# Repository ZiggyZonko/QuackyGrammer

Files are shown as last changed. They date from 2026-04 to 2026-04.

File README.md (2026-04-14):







# QuackyGrammer ~ The portable, Type C PIC Programmer

Recently, I rediscovered a collection of PIC Microcontrollers and was fascinated on how they work, programming them, and the simplicity of a REAL microcontroller. Before this, I was learning assembly through a previous project of mine, LindlesOS, so these microcontrollers were a great way of demonstrating the practicality of Assembly. I picked up a k150 from AliExpress, only to realise the drivers are impossible to find, setup and are mind-numbing to install...

This is what brought me to my project, I was wondering, how could I improve the programming of PIC Microcontrollers while making it portable, and simplistic. I stumbled upon the PICKIT 2 and learnt about the difference between ZIF and ISCP sockets, learning that ISCP was wayyy more accessible, and may be suitable for my project. After countless hours of planning, wondering, and researching I agreed on things to include in my project

- USB Type C Connector ~ Usually on programmers they use USB Type B because of it's constant power rather than being wired to power.
  
- PIC18F2550 ~ The heart and brains of the project. The K150 uses PIC16F628A but I wanted to add further programming capabilities and not include excess chips, like on the K150.
  
- Connector ~ The defining factor of the PICKIT 2 is the ability to plug about 5 wires into the microcontroller, and upload your code from a PICKIT application, which is exactly what I can replicate with this project, for even more accessibility.

Which brings me to my project, QuackyGrammer ✨

The QuackyGrammer is a USB Type C powered, portable, ISCP connecting PIC Programmer, powered by the mighty PIC18F2550. The Programmer is aimed to make PIC Programming easy with a flawless, PICKIT 2 inspired connecting system, and a very portable USB Type C connection port. The duck theme is inspired by a new nickname I recently acquired, Quackery, and as you can tell by my other projects, I stick with this theme now.

The Bill of Materials is in BOM.csv

The firmware for this project, is uploading the PK2V023200.hex into the PIC18F2550 with the PICKITV2 programmer software.

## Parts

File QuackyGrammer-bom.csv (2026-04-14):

Name | Purpose | Quantity | Total Cost (USD) | Link | Distributor
JLCPCB PCB Project | The PCB of the Project | 5 | 2.00 | https://cart.jlcpcb.com/shopcart/cart | JLCPCB
470nF 50VDC Low Leakage Electrolytic Capacitor | VUSB Connection | 1 | 0.34 | https://www.jaycar.com.au/p/RL6410 | Jaycar
47uF 16VDC Electrolytic Capacitor | Power and Boost Module Capacitors | 3 | 0.75 | https://www.jaycar.com.au/p/RE6100 | Jaycar
20.0 MHz Crystal | Crystal Oscillator | 1 | 2.10 | https://www.jaycar.com.au/p/RQ5299 | Jaycar
680uH RF Choke | Inductor For Boost Module | 1 | 0.68 | https://www.jaycar.com.au/p/LF1544 | Jaycar
100nF 50VDC Ceramic Capacitors ~ Pack of 2 | Power Capacitors | 1 | 0.39 | https://www.jaycar.com.au/p/RC5360 | Jaycar
BC548 NPN Transistor | Boost Module | 3 | 0.64 | https://www.jaycar.com.au/p/ZT2154 | Jaycar
BC557 PNP Transistor | Boost Module Transistor | 1 | 0.21 | https://www.jaycar.com.au/p/ZT2164 | Jaycar
6 Pin 0.1 inch Header | The ISCP Header Connection | 1 | 0.68 | https://www.jaycar.com.au/p/HM3406 | Jaycar
28 Pin Production IC Socket | Securing the PIC18F2550 | 1 | 0.53 | https://www.jaycar.com.au/p/PI6510 | Jaycar
Red 3mm LED | Power Off/Error Indicator | 1 | 0.53 | https://www.jaycar.com.au/p/ZD0102 | Jaycar
Green 3mm LED | Green LED for Power On | 1 | 0.53 | https://www.jaycar.com.au/p/ZD0122 | Jaycar
15pF 50VDC Ceramic Capacitors ~ 2 Pack | Crystal Capacitors | 1 | 0.32 | https://www.jaycar.com.au/p/RC5314 | Jaycar
Tactile Switch | Reset Switch for PIC18F2550 | 1 | 0.68 | https://www.jaycar.com.au/p/SP0611 | Jaycar
1N4148 Signal Diode Pack of 5 | Boost Module Diode | 1 | 0.68 | https://www.jaycar.com.au/p/ZR1100 | Jaycar
10uF 25VDC Electrolytic Capacitor | Power Capacitor | 1 | 0.25 | https://www.jaycar.com.au/p/RE6070 | Jaycar
E12 1/4 Watt Resistor Kit | Used for Resistors in the PCB | 1 | 16.34 | https://www.jaycar.com.au/p/RR1697 | Jaycar
5.1k Ohm Resistor Pack of 8 | USB Data Resistor Specifically | 1 | 0.61 | https://www.jaycar.com.au/5-1k-ohm-0-5-watt-metal-film-resistors-pack-of-8/p/RR0589 | Jaycar
USB Connector Type C | The USB connector, giving power and data to the project | 1 | 0.78 | https://www.digikey.com.au/en/products/detail/gct/USB4105-GF-A/11198441 | Digikey
PIC18F2550 | The heart of the project, powering the programming | 1 | 7.04 | https://www.digikey.com.au/en/products/detail/microchip-technology/PIC18F2550-I-SP/704575 | Digikey

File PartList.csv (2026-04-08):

Item | Quantity | Value/Part | Description | Package | Notes
U1 | 1 | PIC18F2550-I/P | Microcontroller DIP-28 | DIP-28 | Main MCU
U1-Socket | 1 | 28-pin IC socket | DIP socket | DIP-28 | For MCU
J1 | 1 | USB-C Receptacle (USB2.0) | USB connector | USB-C TH/SMD | Power + data
J2 | 1 | Pin Header 1x6 | ICSP Header | 2.54mm | Programming header
Y1 | 1 | 20MHz Crystal | Crystal oscillator | HC-49 | Clock
C1-C2 | 2 | 15pF | Ceramic capacitor | Through-hole | Crystal caps
C3-C4 | 2 | 100nF | Ceramic capacitor | Through-hole | Decoupling
C5-C6 | 2 | 47uF 16V | Electrolytic capacitor | Radial | Power smoothing
C7 | 1 | 10uF 16V | Electrolytic capacitor | Radial | Power
C8 | 1 | 470nF | Ceramic capacitor | Through-hole | USB filter
R1-R2 | 2 | 22Ω | Resistor | Through-hole | USB data lines
R3-R4 | 2 | 5.1kΩ | Resistor | Through-hole | USB-C CC pull-down
R5-R7 | 3 | 33Ω | Resistor | Through-hole | General
R8 | 1 | 100Ω | Resistor | Through-hole | General
R9 | 1 | 1kΩ | Resistor | Through-hole | General
R10 | 1 | 2.7kΩ | Resistor | Through-hole | General
R11-R12 | 2 | 4.7kΩ | Resistor | Through-hole | General
R13-R15 | 3 | 10kΩ | Resistor | Through-hole | General
R16 | 1 | 100kΩ | Resistor | Through-hole | General
R17-R18 | 2 | 330Ω | Resistor | Through-hole | LED current limit
D1-D2 | 2 | 1N4148 | Diode | DO-35 | Signal diode
Q1-Q3 | 3 | BC548 | NPN Transistor | TO-92 | VPP circuit
Q4 | 1 | BC557 | PNP Transistor | TO-92 | VPP circuit
L1 | 1 | 680uH | Inductor | Axial | Boost circuit
LED1 | 1 | Green LED | Indicator LED | 3mm | Status
LED2 | 1 | Red LED | Indicator LED | 3mm | Status
SW1 | 1 | Tactile Switch | Push button | Through-hole | User input
HW1 | 4 | M3x10mm Screw | Machine screw | Metal | Case assembly

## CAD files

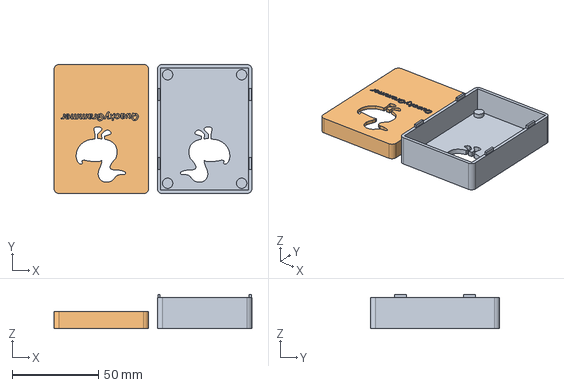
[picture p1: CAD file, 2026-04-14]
Model/QuackyGrammerModelOnly.step
115.0 x 75.0 x 20.0 mm

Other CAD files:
Model/QuackGrammer.step

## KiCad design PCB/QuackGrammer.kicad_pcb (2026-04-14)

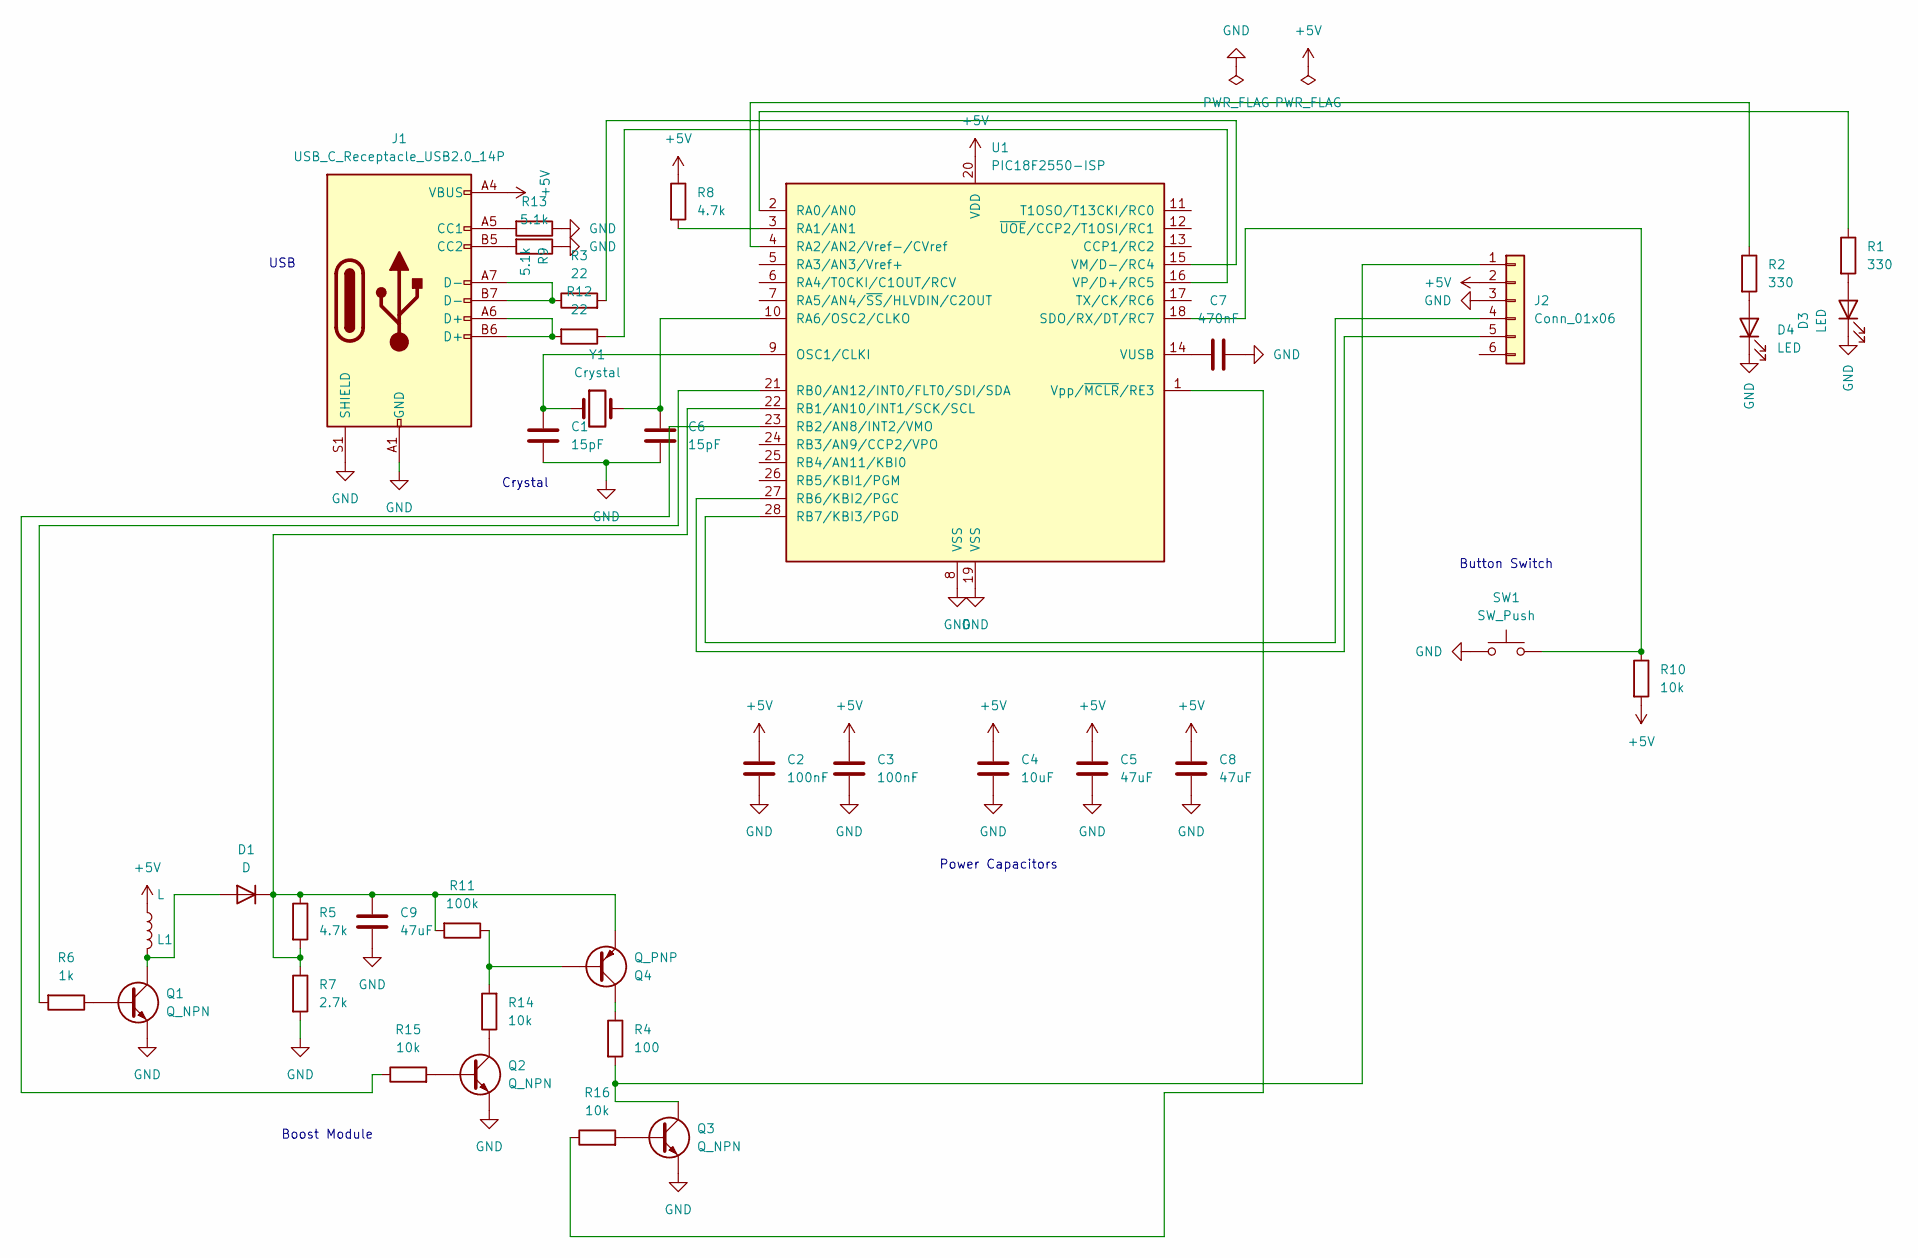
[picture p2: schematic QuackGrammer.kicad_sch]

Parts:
C1, C6: 15pF; C_Disc_D5.0mm_W2.5mm_P5.00mm
C2, C3: 100nF; C_Disc_D5.0mm_W2.5mm_P5.00mm
C4: 10uF; CP_Radial_D5.0mm_P2.50mm
C5, C8, C9: 47uF; CP_Radial_D5.0mm_P2.50mm
C7: 470nF; C_Disc_D5.0mm_W2.5mm_P5.00mm
D1: D; D_DO-35_SOD27_P7.62mm_Horizontal
D3, D4: LED; LED_D3.0mm
J1: USB_C_Receptacle_USB2.0_14P; USB_C_Receptacle_GCT_USB4105-xx-A_16P_TopMnt_Horizontal
J2: Conn_01x06; PinHeader_1x06_P2.54mm_Horizontal
L1: L; R_Axial_DIN0207_L6.3mm_D2.5mm_P7.62mm_Horizontal
Q1, Q2, Q3: Q_NPN; TO-92_Inline
Q4: Q_PNP; TO-92_Inline
R1, R2: 330; R_Axial_DIN0207_L6.3mm_D2.5mm_P7.62mm_Horizontal
R3, R12: 22; R_Axial_DIN0207_L6.3mm_D2.5mm_P7.62mm_Horizontal
R4: 100; R_Axial_DIN0207_L6.3mm_D2.5mm_P7.62mm_Horizontal
R5, R8: 4.7k; R_Axial_DIN0207_L6.3mm_D2.5mm_P7.62mm_Horizontal
R6: 1k; R_Axial_DIN0207_L6.3mm_D2.5mm_P7.62mm_Horizontal
R7: 2.7k; R_Axial_DIN0207_L6.3mm_D2.5mm_P7.62mm_Horizontal
R9, R13: 5.1k; R_Axial_DIN0207_L6.3mm_D2.5mm_P7.62mm_Horizontal
R10, R14, R15, R16: 10k; R_Axial_DIN0207_L6.3mm_D2.5mm_P7.62mm_Horizontal
R11: 100k; R_Axial_DIN0207_L6.3mm_D2.5mm_P7.62mm_Horizontal
SW1: SW_Push; SW_PUSH_6mm
U1: PIC18F2550-ISP; DIP-28_W7.62mm
Y1: Crystal; Crystal_HC49-U_Vertical

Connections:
+5V: C2.1, C3.1, C4.1, C5.1, C8.1, J1.A4 (VBUS), J1.A9 (VBUS), J1.B4 (VBUS), J1.B9 (VBUS), J2.2, L1.2, R8.1, R10.2, U1.20 (VDD)
GND: C1.2, C2.2, C3.2, C4.2, C5.2, C6.2, C7.1, C8.2, C9.2, D3.1 (K), D4.1 (K), J1.A1 (GND), J1.A12 (GND), J1.B1 (GND), J1.B12 (GND), J1.S1 (SHIELD), J2.3, Q1.3 (E), Q2.3 (E), Q3.3 (E), R7.2, R9.1, R13.1, SW1.1, U1.8 (VSS), U1.19 (VSS)
unnamed: D1.2 (A), L1.1, Q1.1 (C)
unnamed: C9.1, D1.1 (K), Q4.3 (E), R5.1, R5.2, R7.1, R11.2, U1.22 (RB1/AN10/INT1/SCK/SCL)
unnamed: D3.2 (A), R1.2
unnamed: D4.2 (A), R2.2
unnamed: J1.A5 (CC1), R9.2
unnamed: J1.B5 (CC2), R13.2
unnamed: J1.A6 (D+), J1.B6 (D+), R12.2
unnamed: J1.A7 (D-), J1.B7 (D-), R3.1
unnamed: J2.1, Q3.1 (C), R4.2
unnamed: J2.4, U1.28 (RB7/KBI3/PGD)
unnamed: J2.5, U1.27 (RB6/KBI2/PGC)
unnamed: Q1.2 (B), R6.1
unnamed: Q2.2 (B), R15.2
unnamed: Q2.1 (C), R14.1
unnamed: Q3.2 (B), R16.2
unnamed: Q4.2 (B), R11.1, R14.2
unnamed: Q4.1 (C), R4.1
unnamed: C1.1, U1.9 (OSC1/CLKI), Y1.1
unnamed: R1.1, U1.2 (RA0/AN0)
unnamed: R8.2, U1.3 (RA1/AN1)
unnamed: R2.1, U1.4 (RA2/AN2/Vref-/CVref)
unnamed: C6.1, U1.10 (RA6/OSC2/CLKO), Y1.2
unnamed: R6.2, U1.21 (RB0/AN12/INT0/FLT0/SDI/SDA)
unnamed: R15.1, U1.23 (RB2/AN8/INT2/VMO)
unnamed: R10.1, SW1.2, U1.18 (SDO/RX/DT/RC7)
unnamed: R3.2, U1.15 (VM/D-/RC4)
unnamed: R12.1, U1.16 (VP/D+/RC5)
unnamed: C7.2, U1.14 (VUSB)
unnamed: R16.1, U1.1 (Vpp/~MCLR/RE3)

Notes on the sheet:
Boost Module
Power Capacitors
Button Switch
Crystal
USB

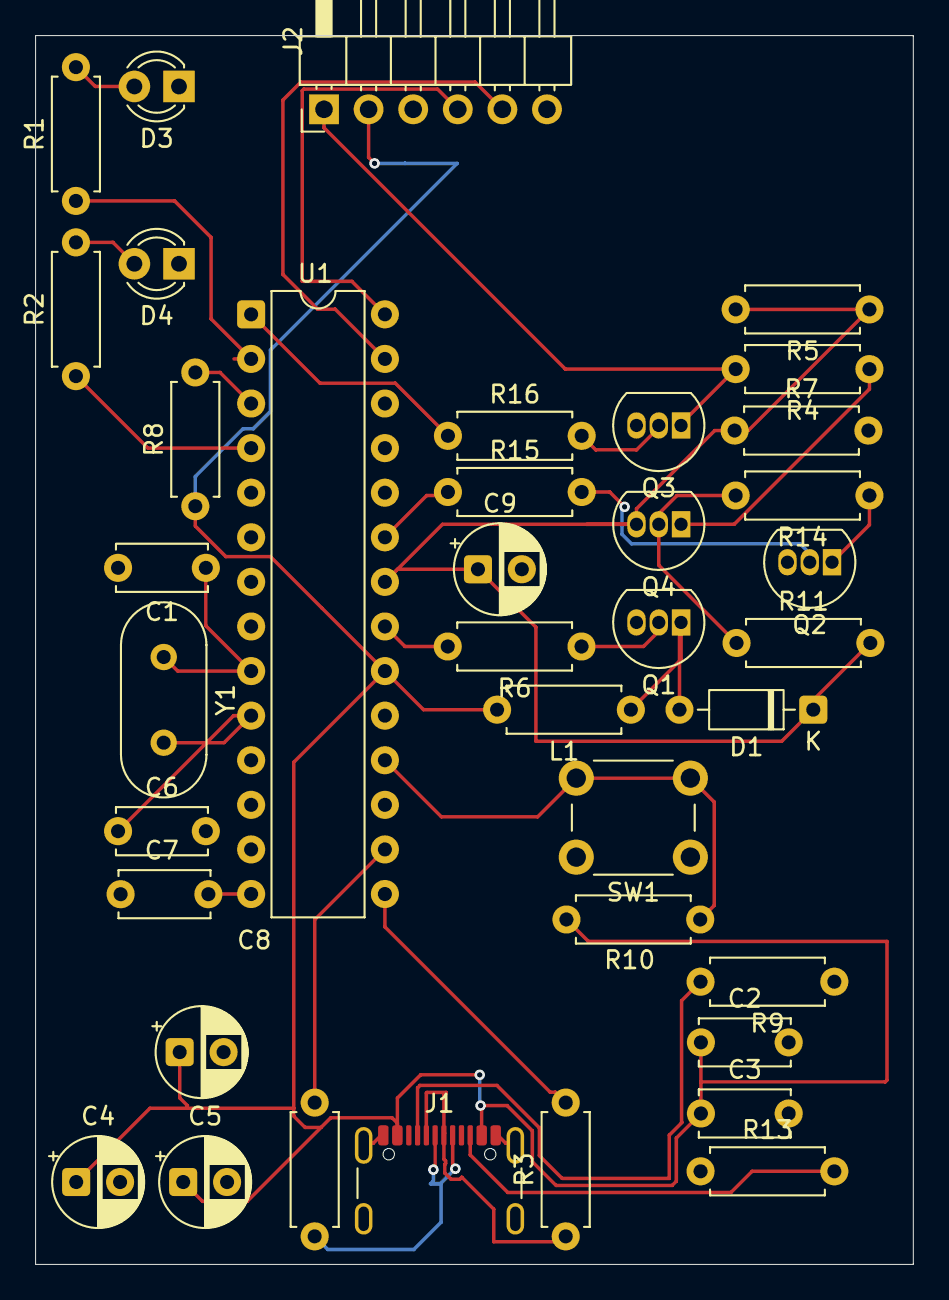
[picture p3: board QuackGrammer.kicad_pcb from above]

Board: 2 copper layers, 50.0 x 70.0 mm, 38 parts (0 on the bottom side), 31 nets.

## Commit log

2026-04-08 BOM created
    [BOM.csv]
2026-04-14 Rename QuackyGrammer-bom (1).csv to QuackyGrammer-bom.csv
    [QuackyGrammer-bom.csv]
